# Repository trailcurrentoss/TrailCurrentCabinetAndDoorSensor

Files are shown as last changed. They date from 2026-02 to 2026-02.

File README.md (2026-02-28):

# TrailCurrent Cabinet and Door Sensor

Sensor module that monitors cabinet and door open/closed states using reed switches and reports status over a CAN bus interface. Part of the [TrailCurrent](https://trailcurrent.com) open-source vehicle platform.

## Hardware Overview

- **Microcontroller:** ESP32-C6
- **Function:** Cabinet and door state monitoring with CAN bus reporting
- **Key Features:**
  - 10 reed switch inputs for open/closed detection
  - CAN bus communication at 500 kbps
  - DIP switch selectable CAN address (up to 8 modules per bus)
  - Over-the-air (OTA) firmware updates via WiFi (triggered over CAN)
  - RGB LED status indicator
  - Custom flash partition layout with dual OTA slots
  - FreeCAD enclosure design

### Design Specifications

- **Operating Temperature:** -20°C to +70°C
- **Power:** 12V vehicle house battery via 5V DC-DC converter and 3.3V regulator
- **Data Rate:** 5 transmissions per second
- **Target Cost:** < $5 per unit

## CAN Bus Addressing

Each module uses a 3-position DIP switch to select its CAN message ID from a reserved block of 8 IDs (0x0A-0x11). This allows up to 8 modules on the same CAN bus, each reporting the state of up to 10 doors/cabinets.

| DIP SW3 | DIP SW2 | DIP SW1 | Address | CAN ID | DBC Message Name |
|---|---|---|---|---|---|
| OFF | OFF | OFF | 0 | 0x0A | CabinetDoorStatus0 |
| OFF | OFF | ON | 1 | 0x0B | CabinetDoorStatus1 |
| OFF | ON | OFF | 2 | 0x0C | CabinetDoorStatus2 |
| OFF | ON | ON | 3 | 0x0D | CabinetDoorStatus3 |
| ON | OFF | OFF | 4 | 0x0E | CabinetDoorStatus4 |
| ON | OFF | ON | 5 | 0x0F | CabinetDoorStatus5 |
| ON | ON | OFF | 6 | 0x10 | CabinetDoorStatus6 |
| ON | ON | ON | 7 | 0x11 | CabinetDoorStatus7 |

DIP switch position 4 enables the 120-ohm CAN bus termination resistor.

### CAN Message Format

Each module transmits a 2-byte message at 5 Hz (200 ms interval):

| Byte | Bits  | Description |
|---|---|---|
| 0 | 0-7 | Door status 1-8 (RSW01-RSW08) |
| 1 | 0-1 | Door status 9-10 (RSW09-RSW10) |
| 1 | 2-7 | Reserved |

Each bit represents one reed switch: `1` = door open, `0` = door closed.

### CAN Control Messages

The module also listens for control messages from other nodes:

- **CAN ID 0x00 - OTA Update Notification:** Contains a 3-byte MAC address suffix. If it matches this module's hostname, the module connects to WiFi using stored credentials and enters OTA update mode.
- **CAN ID 0x01 - WiFi Credential Configuration:** Multi-message protocol to receive and store WiFi SSID and password in NVS flash for future OTA updates.

## Hardware Requirements

### Components

- **Microcontroller:** ESP32-C6-Super-Mini
- **CAN Transceiver:** SN65HVD230
- **Sensors:** Normally Open (NO) reed switches
- **Address Selection:** 4-position DIP switch (3 address bits + CAN termination)
- **Power:** Buck converter (12V to 5V to 3.3V)
- **Connectors:** JST XH 2.54 4-pin

### KiCAD Library Dependencies

This project uses the consolidated [TrailCurrentKiCADLibraries](https://github.com/trailcurrentoss/TrailCurrentKiCADLibraries).

**Setup:**

```bash
# Clone the library alongside this project
git clone git@github.com:trailcurrentoss/TrailCurrentKiCADLibraries.git

# Set environment variables (add to ~/.bashrc or ~/.zshrc)
# Adjust paths to where you cloned the library
export TRAILCURRENT_SYMBOL_DIR="../TrailCurrentKiCADLibraries/symbols"
export TRAILCURRENT_FOOTPRINT_DIR="../TrailCurrentKiCADLibraries/footprints"
export TRAILCURRENT_3DMODEL_DIR="../TrailCurrentKiCADLibraries/3d_models"
```

See [KICAD_ENVIRONMENT_SETUP.md](https://github.com/trailcurrentoss/TrailCurrentKiCADLibraries/blob/main/KICAD_ENVIRONMENT_SETUP.md) in the library repository for detailed setup instructions.

### GPIO Pin Assignments

| GPIO  | Function | Notes |
|---|---|---|
| 0-7 | RSW03-RSW10 | Reed switch inputs (internal pull-up) |
| 8 | RGB LED | Built-in WS2812 on ESP32-C6 SuperMini |
| 14 | CAN TX | To SN65HVD230 transceiver |
| 15 | CAN RX | From SN65HVD230 transceiver |
| 16 | RSW01 | TX pin, free since USB CDC is used |
| 17 | RSW02 | RX pin, free since USB CDC is used |
| 18-20 | ADDR01-03 | DIP switch address bits (internal pull-up)|

## Opening the Project

1. **Set up environment variables** (see Library Dependencies above)
2. **Open KiCAD:**
   ```bash
   kicad EDA/TrailCurrentCabinetAndDoorSensorModule/TrailCurrentCabinetAndDoorSensorModule.kicad_pro
   ```
3. **Verify libraries load** - All symbol and footprint libraries should resolve without errors
4. **View 3D models** - Open PCB and press `Alt+3` to view the 3D visualization

## Firmware

See `src/` directory for PlatformIO-based firmware.

**Setup:**
```bash
# Install PlatformIO (if not already installed)
pip install platformio

# Build firmware
pio run

# Upload to board (serial)
pio run -t upload

# Upload via OTA (after initial flash)
pio run -t upload --upload-port esp32c6-DEVICE_ID
```

### Firmware Dependencies

This firmware depends on the following public libraries:

- **[C6SuperMiniRgbLedLibrary](https://github.com/trailcurrentoss/C6SuperMiniRgbLedLibrary)** (v0.0.1) - RGB LED status indicator driver
- **[Esp32C6OtaUpdateLibrary](https://github.com/trailcurrentoss/Esp32C6OtaUpdateLibrary)** (v0.0.1) - Over-the-air firmware update functionality
- **[Esp32C6TwaiTaskBasedLibrary](https://github.com/trailcurrentoss/Esp32C6TwaiTaskBasedLibrary)** (v0.0.3) - CAN bus communication interface
- **[ESP32ArduinoDebugLibrary](https://github.com/trailcurrentoss/ESP32ArduinoDebugLibrary)** - Debug macros with compile-time removal

All dependencies are automatically resolved by PlatformIO during the build process.

## Manufacturing

- **PCB Files:** Ready for fabrication via standard PCB services (JLCPCB, OSH Park, etc.)
- **BOM Generation:** Export BOM from KiCAD schematic (Tools > Generate BOM)
- **Enclosure:** FreeCAD design included in `CAD/` directory
- **JLCPCB Assembly:** See [BOM_ASSEMBLY_WORKFLOW.md](https://github.com/trailcurrentoss/TrailCurrentKiCADLibraries/blob/main/BOM_ASSEMBLY_WORKFLOW.md) for detailed assembly workflow

## Documentation

- **Requirements:** See `DOCS/Requirements/high-level-requirements.md` for detailed specifications

## Project Structure

```
├── CAD/                          # FreeCAD enclosure design
├── DOCS/                         # Requirements documentation
│   └── Requirements/
│       └── high-level-requirements.md
├── EDA/                          # KiCAD hardware design files
│   └── TrailCurrentCabinetAndDoorSensorModule/
│       ├── *.kicad_pro           # KiCAD project
│       ├── *.kicad_sch           # Schematic
│       └── *.kicad_pcb           # PCB layout
├── src/                          # Firmware source
│   └── main.cpp                  # Main application
├── platformio.ini                # Build configuration
└── partitions.csv                # ESP32 flash partition layout
```

## License

MIT License - See LICENSE file for details.

This is open source hardware. You are free to use, modify, and distribute these designs for personal or commercial purposes.

## Contributing

Improvements and contributions are welcome! Please submit issues or pull requests.

## Support

For questions about:
- **KiCAD setup:** See [KICAD_ENVIRONMENT_SETUP.md](https://github.com/trailcurrentoss/TrailCurrentKiCADLibraries/blob/main/KICAD_ENVIRONMENT_SETUP.md)
- **Assembly workflow:** See [BOM_ASSEMBLY_WORKFLOW.md](https://github.com/trailcurrentoss/TrailCurrentKiCADLibraries/blob/main/BOM_ASSEMBLY_WORKFLOW.md)

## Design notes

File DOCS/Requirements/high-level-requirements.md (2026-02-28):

# High-Level Design (HLD) Document

## 1. Project Overview

**Project Title:** Cabinet and Door Sensing Module

**Description:** A microcontroller-based system that monitors the status of doors and cabinets. It will be used to make the high level system contextually aware of which doors and or cabinets are currently open or closed.

**Objective:**  
To design and implement a reliable, low-power, and cost-effective microcontroller-based system for cabinet and door status monitoring that can operate autonomously and send data over the CAN bus.

---

## 2. Microcontroller Selection

**Selected Microcontroller:**  
**ESP32C6**  
[Datasheet](https://documentation.espressif.com/esp32-c6_datasheet_en.pdf)

**Rationale for Selection:**  
- Power efficient and built in can transceiver.  
- Low price point and availability as MCU, Module, or small footprint dev board.  
- Low power consumption.  
- Strong ecosystem and development support.

---

## 3. System Requirements

### 3.1 Functional Requirements

| Requirement | Description |
|---|---|
| Door Sensing | Read and send over CAN bus the door or cabinet status |
| Data Transmission | Send collected data to the rest of the network via CAN protocol |
| Power Management | Support for low-power modes to reduce load on installed environment |

### 3.2 Non-Functional Requirements

| Requirement | Description |
|---|---|
| Reliability | System must operate continuously without disruption indefinitely for solar installs |
| CAN Bus Data Usage | **Needs calculation to see what is available on a 500k CAN Bus.** |
| Environmental Tolerance | Operate within -20°C to +70°C |
| Cost | Target cost < $5 per unit |
---

## 4. System Architecture Overview

### 4.1 Hardware Components

| Component | Description |
|---|---|
| ESP32C6 | Main microcontroller |
| Reed Swith | Any brand should suffice, justt needs to provide an on/off state to trigger correctly. |

### 4.2 Software Components

| Component | Description |
|---|---|
| Main Application | Main data collection, and transmission |
| Sensor Drivers | Interface with reed switches |
| Communication Stack | CAN Bus coomunication implementation |
| OTA | Over the air update capabilities with trigger coming from CAN Bus. |

---

## 5. Communication Protocol

- **CAN Bus:** CAN Bus protocol used to transmit data  
- **Data Format:** Binary representation of each sensor status
- **Transmission Frequency:** 5 times per second to avoid delayed notification of doors changing status during travel.
---

## 6. Power Management Strategy

- **Battery:** Connected to house battery of implemented vehicle.
- **Power Supply Circuit:** 5V DC to DC buck converter with 3.3V regulator (e.g., AMS1117)  
---

## 7. Development Tools and Environment

| Tool | Description |
|---|---|
| PioArduino | Development IDE |
| Arduino | Framework used for firmware |
| KiCAD | EDA Design tool for schematic and PCB |
| FreeCAD | CAD tool used for enclosure design |
| Version Control | Git with GitHub for repo and source control |
| Documentation Tools | Markdown |

---

## 8. Testing and Validation

| Test Type | Description |
|---|---|
| Unit Testing | Test individual modules (e.g., sensor drivers, communication stack) |
| Integration Testing | Ensure all components work together as expected |
| Performance Testing | Measure power consumption, response time, and data accuracy |
---

## 9. Future Enhancements

- Add GPS module for location tracking  
- Support for multiple sensors (e.g., PM2.5, CO2)  
- Edge computing for local data processing  
- Integration with IoT platforms (e.g., AWS IoT, Azure IoT Hub)  
- Mobile app integration for real-time monitoring

---

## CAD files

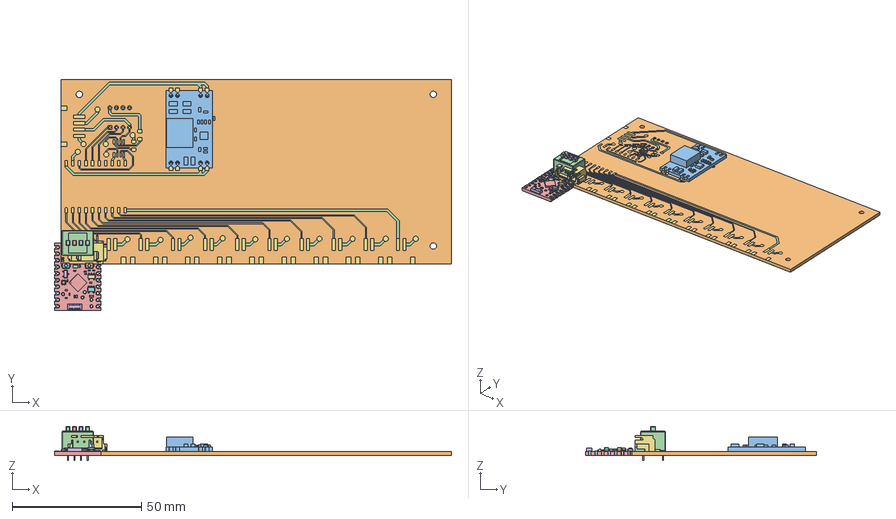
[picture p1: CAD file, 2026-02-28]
CAD/TrailCurrentCabinetAndDoorSensorModuleEDA.FCStd
153.4 x 89.4 x 13.2 mm
SxB-XH-SM4-TB
SxB-XH-SM4-TB001
SxB-XH-SM4-TB002
BODY-SO
LEAD-D0008A
LEAD-D0008A001
LEAD-D0008A002
LEAD-D0008A003
LEAD-D0008A004
LEAD-D0008A005
LEAD-D0008A006
LEAD-D0008A007
PCB
USB_C_Receptacle_16P_TopMnt_Horizontal_GCT_USB4105-xx-A037
USB_C_Receptacle_16P_TopMnt_Horizontal_GCT_USB4105-xx-A038
USB_C_Receptacle_16P_TopMnt_Horizontal_GCT_USB4105-xx-A039
USB_C_Receptacle_16P_TopMnt_Horizontal_GCT_USB4105-xx-A040
USB_C_Receptacle_16P_TopMnt_Horizontal_GCT_USB4105-xx-A041
USB_C_Receptacle_16P_TopMnt_Horizontal_GCT_USB4105-xx-A042
USB_C_Receptacle_16P_TopMnt_Horizontal_GCT_USB4105-xx-A043
USB_C_Receptacle_16P_TopMnt_Horizontal_GCT_USB4105-xx-A044
USB_C_Receptacle_16P_TopMnt_Horizontal_GCT_USB4105-xx-A045
USB_C_Receptacle_16P_TopMnt_Horizontal_GCT_USB4105-xx-A046
USB_C_Receptacle_16P_TopMnt_Horizontal_GCT_USB4105-xx-A047
USB_C_Receptacle_16P_TopMnt_Horizontal_GCT_USB4105-xx-A048
USB_C_Receptacle_16P_TopMnt_Horizontal_GCT_USB4105-xx-A049
USB_C_Receptacle_16P_TopMnt_Horizontal_GCT_USB4105-xx-A050
USB_C_Receptacle_16P_TopMnt_Horizontal_GCT_USB4105-xx-A051
USB_C_Receptacle_16P_TopMnt_Horizontal_GCT_USB4105-xx-A052
USB_C_Receptacle_16P_TopMnt_Horizontal_GCT_USB4105-xx-A053
USB_C_Receptacle_16P_TopMnt_Horizontal_GCT_USB4105-xx-A054
USB_C_Receptacle_16P_TopMnt_Horizontal_GCT_USB4105-xx-A055
USB_C_Receptacle_16P_TopMnt_Horizontal_GCT_USB4105-xx-A056
USB_C_Receptacle_16P_TopMnt_Horizontal_GCT_USB4105-xx-A057
USB_C_Receptacle_16P_TopMnt_Horizontal_GCT_USB4105-xx-A058
USB_C_Receptacle_16P_TopMnt_Horizontal_GCT_USB4105-xx-A059
USB_C_Receptacle_16P_TopMnt_Horizontal_GCT_USB4105-xx-A060
USB_C_Receptacle_16P_TopMnt_Horizontal_GCT_USB4105-xx-A061
USB_C_Receptacle_16P_TopMnt_Horizontal_GCT_USB4105-xx-A062
USB_C_Receptacle_16P_TopMnt_Horizontal_GCT_USB4105-xx-A063
USB_C_Receptacle_16P_TopMnt_Horizontal_GCT_USB4105-xx-A064
USB_C_Receptacle_16P_TopMnt_Horizontal_GCT_USB4105-xx-A065
USB_C_Receptacle_16P_TopMnt_Horizontal_GCT_USB4105-xx-A066
USB_C_Receptacle_16P_TopMnt_Horizontal_GCT_USB4105-xx-A067
USB_C_Receptacle_16P_TopMnt_Horizontal_GCT_USB4105-xx-A068
USB_C_Receptacle_16P_TopMnt_Horizontal_GCT_USB4105-xx-A069
USB_C_Receptacle_16P_TopMnt_Horizontal_GCT_USB4105-xx-A070
USB_C_Receptacle_16P_TopMnt_Horizontal_GCT_USB4105-xx-A071
USB_C_Receptacle_16P_TopMnt_Horizontal_GCT_USB4105-xx-A072
Button_black_002
Button_black_003
io23
io21
io22
io12
io13
Corps
Corps001
Corps002
Corps003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

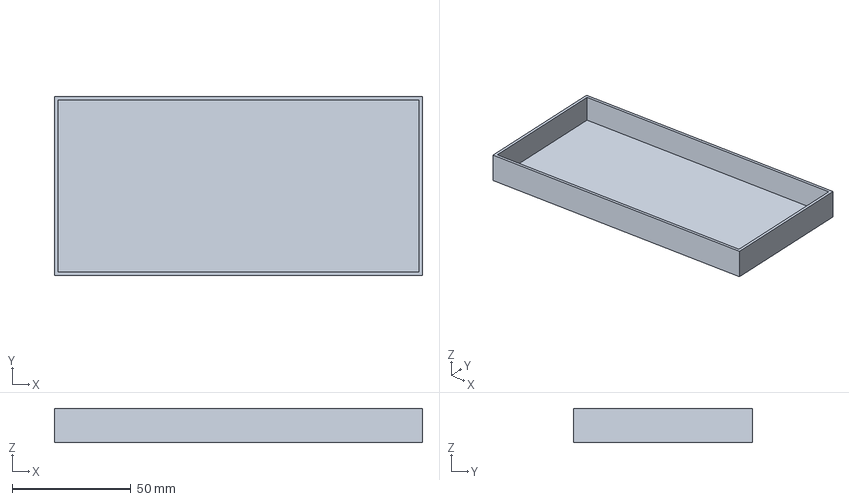
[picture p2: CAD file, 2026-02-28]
CAD/TrailCurrentCabinetAndDoorSensorModuleHousing.FCStd
154.8 x 75.2 x 14.5 mm

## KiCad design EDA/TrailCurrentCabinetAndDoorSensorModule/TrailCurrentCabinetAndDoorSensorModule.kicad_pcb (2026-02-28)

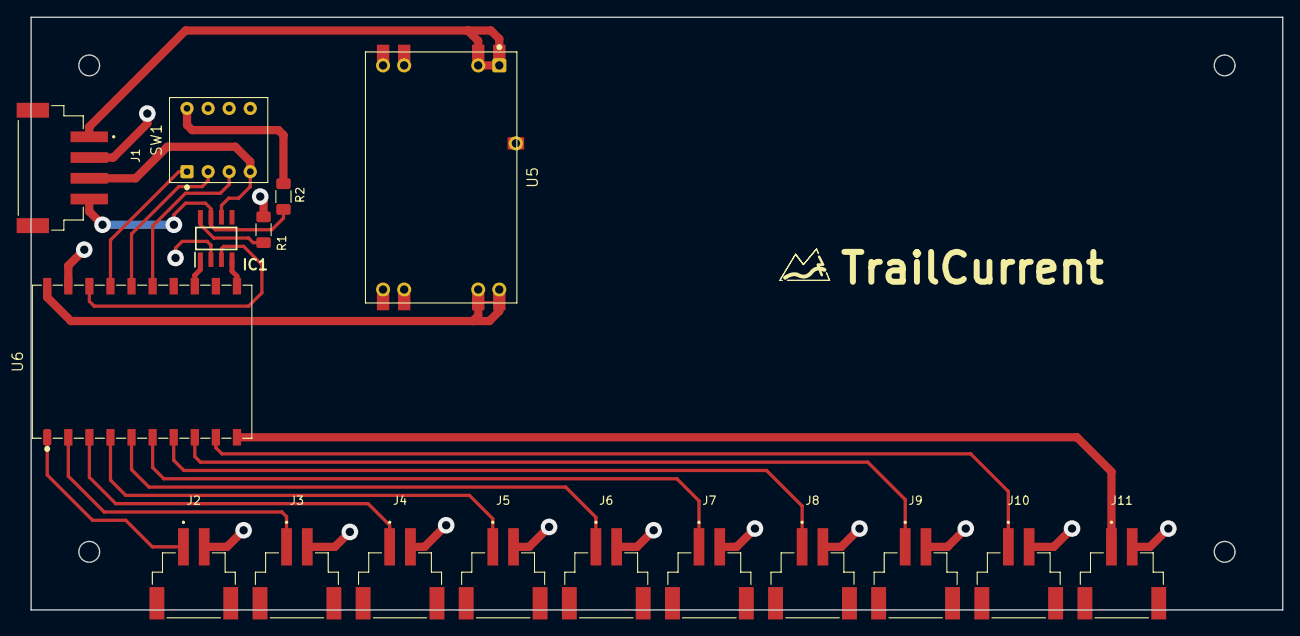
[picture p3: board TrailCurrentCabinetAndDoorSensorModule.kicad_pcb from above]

Board: 2 copper layers, 150.8 x 71.4 mm, 19 parts (0 on the bottom side), 23 nets.

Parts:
IC1: SN65HVD230DR
J1: S4B-XH-SM4-TB; JST_S4B-XH-SM4-TB
J2, J3, J4, J5, J6, J7, J8, J9, J10, J11: S2B-XH-SM4-TB; JST_S2B-XH-SM4-TB
LOGO: TrailCurrentLogo_Text
LOGO#2: TrailCurrentLogo_Icon
R1: 10k; R_1206_3216Metric_Pad1.30x1.75mm_HandSolder
R2: 120; R_1206_3216Metric_Pad1.30x1.75mm_HandSolder
SW1: DS-04
U5: Mini560
U6: ESP32-C6-SuperMini; ESP32-C6-SuperMini_SMD

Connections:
+3.3V: IC1.3 (VCC), U6.13 (3V3)
+5V: U5.8 (VOUT+), U5.9 (VOUT+), U6.11 (5V)
+12V: J1.1, U5.1 (VIN+), U5.2 (VIN+)
ADDR01: SW1.3, U6.16 (GPIO18)
ADDR02: SW1.2, U6.15 (GPIO19)
ADDR03: SW1.1, U6.14 (GPIO20)
CANH: IC1.7 (CANH), J1.4, R2.1
CANL: IC1.6 (CANL), J1.3, SW1.4
CAN_RX: IC1.4 (R), U6.20 (GPIO8)
CAN_TX: IC1.1 (D), U6.18 (GPIO14)
GND: IC1.2 (GND), J1.2, J2.2, J3.2, J4.2, J5.2, J6.2, J7.2, J8.2, J9.2, J10.2, J11.2, R1.1, SW1.5, SW1.6, SW1.7, U5.3 (GND), U5.4 (GND), U5.6 (GND), U5.7 (GND), U6.12 (GND)
unnamed: IC1.8 (RS), R1.2
unnamed: R2.2, SW1.8
RSW01: J2.1, U6.1 (TX)
RSW02: J3.1, U6.2 (RX)
RSW03: J4.1, U6.3 (GPIO0)
RSW04: J5.1, U6.4 (GPIO1)
RSW05: J6.1, U6.5 (GPIO2)
RSW06: J7.1, U6.6 (GPIO3)
RSW07: J8.1, U6.7 (GPIO4)
RSW08: J9.1, U6.8 (GPIO5)
RSW09: J10.1, U6.9 (GPIO6)
RSW10: J11.1, U6.10 (GPIO7)

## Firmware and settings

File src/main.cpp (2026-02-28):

#include <Arduino.h>
#include <debug.h>
#include "OtaUpdate.h"
#include "RgbLed.h"
#include "TwaiTaskBased.h"
#include <Preferences.h>
#include <driver/gpio.h>

// =============================================================================
// Pin Definitions (from schematic global labels)
// =============================================================================

// Reed switch inputs (Normally Open - close when magnet nearby / door closed)
// HIGH = door open, LOW = door closed (using internal pull-ups)
static const gpio_num_t RSW_PINS[] = {
  GPIO_NUM_16,  // RSW01 (TX pin - free since USB CDC is used for Serial)
  GPIO_NUM_17,  // RSW02 (RX pin - free since USB CDC is used for Serial)
  GPIO_NUM_0,   // RSW03
  GPIO_NUM_1,   // RSW04
  GPIO_NUM_2,   // RSW05
  GPIO_NUM_3,   // RSW06
  GPIO_NUM_4,   // RSW07
  GPIO_NUM_5,   // RSW08
  GPIO_NUM_6,   // RSW09
  GPIO_NUM_7,   // RSW10
};
static const uint8_t NUM_RSW = sizeof(RSW_PINS) / sizeof(RSW_PINS[0]);

// DIP switch address pins (active LOW - switches pull to GND when ON)
static const gpio_num_t ADDR_PINS[] = {
  GPIO_NUM_18,  // ADDR01 (bit 0 - LSB)
  GPIO_NUM_19,  // ADDR02 (bit 1)
  GPIO_NUM_20,  // ADDR03 (bit 2 - MSB)
};
static const uint8_t NUM_ADDR_PINS = sizeof(ADDR_PINS) / sizeof(ADDR_PINS[0]);

// CAN bus pins
static const gpio_num_t CAN_TX_PIN = GPIO_NUM_14;
static const gpio_num_t CAN_RX_PIN = GPIO_NUM_15;

// RGB LED (built-in WS2812 on GPIO8)
static const uint8_t RGB_LED_PIN = 8;

// =============================================================================
// CAN Bus Configuration
// =============================================================================

// CAN IDs 0x0A-0x11 reserved for up to 8 Cabinet/Door Sensor modules.
// Higher priority (lower ID) than DeviceStatusReport (0x1B).
// DIP switches select offset: CAN_ID = CAN_BASE_ID + dip_value (0-7)
static const uint32_t CAN_BASE_ID = 0x0A;
static const uint32_t CAN_BAUDRATE = 500000;

// Transmit interval (200ms = 5 Hz)
static const unsigned long TX_INTERVAL_MS = 200;

// Debounce time for reed switch readings
static const unsigned long DEBOUNCE_MS = 50;

// =============================================================================
// Global State
// =============================================================================

RgbLed statusLed(RGB_LED_PIN);
OtaUpdate otaUpdate(statusLed, 180000, "", "");

uint32_t canMessageId = CAN_BASE_ID;
unsigned long lastTxTime = 0;

// Debounced reed switch state
uint16_t debouncedState = 0;
uint16_t lastRawState = 0;
unsigned long lastChangeTime = 0;

// WiFi credential reception state (CAN ID 0x01 protocol)
bool wifiConfigInProgress = false;
uint8_t wifiSsidBuffer[33];
uint8_t wifiPasswordBuffer[64];
uint8_t wifiSsidLen = 0;
uint8_t wifiPasswordLen = 0;
uint8_t wifiSsidReceived = 0;
uint8_t wifiPasswordReceived = 0;

// =============================================================================
// WiFi Credential Storage
// =============================================================================

void saveWifiCredentials(const char* ssid, const char* password) {
  Preferences prefs;
  prefs.begin("wifi", false);
  prefs.putString("ssid", ssid);
  prefs.putString("password", password);
  prefs.end();
  debugf("[WiFi] Credentials saved to NVS (SSID: %s)\n", ssid);
}

void handleWifiConfigMessage(const twai_message_t &msg) {
  uint8_t msgType = msg.data[0];

  switch (msgType) {
    case 0x01: {
      wifiSsidLen = msg.data[1];
      wifiPasswordLen = msg.data[2];
      wifiSsidReceived = 0;
      wifiPasswordReceived = 0;
      memset(wifiSsidBuffer, 0, sizeof(wifiSsidBuffer));
      memset(wifiPasswordBuffer, 0, sizeof(wifiPasswordBuffer));
      wifiConfigInProgress = true;
      debugf("[WiFi] Config start: SSID len=%d, Password len=%d\n",
             wifiSsidLen, wifiPasswordLen);
      break;
    }
    case 0x02: {
      if (!wifiConfigInProgress) break;
      uint8_t dataBytes = msg.data_length_code - 2;
      uint8_t remaining = wifiSsidLen - wifiSsidReceived;
      if (dataBytes > remaining) dataBytes = remaining;
      if (wifiSsidReceived + dataBytes <= 32) {
        memcpy(wifiSsidBuffer + wifiSsidReceived, &msg.data[2], dataBytes);
        wifiSsidReceived += dataBytes;
      }
      break;
    }
    case 0x03: {
      if (!wifiConfigInProgress) break;
      uint8_t dataBytes = msg.data_length_code - 2;
      uint8_t remaining = wifiPasswordLen - wifiPasswordReceived;
      if (dataBytes > remaining) dataBytes = remaining;
      if (wifiPasswordReceived + dataBytes <= 63) {
        memcpy(wifiPasswordBuffer + wifiPasswordReceived, &msg.data[2], dataBytes);
        wifiPasswordReceived += dataBytes;
      }
      break;
    }
    case 0x04: {
      if (!wifiConfigInProgress) break;
      wifiConfigInProgress = false;

      uint8_t checksum = 0;
      for (uint8_t i = 0; i < wifiSsidReceived; i++) checksum ^= wifiSsidBuffer[i];
      for (uint8_t i = 0; i < wifiPasswordReceived; i++) checksum ^= wifiPasswordBuffer[i];

      if (checksum == msg.data[1] &&
          wifiSsidReceived == wifiSsidLen &&
          wifiPasswordReceived == wifiPasswordLen) {
        wifiSsidBuffer[wifiSsidReceived] = '\0';
        wifiPasswordBuffer[wifiPasswordReceived] = '\0';
        saveWifiCredentials((const char*)wifiSsidBuffer,
                            (const char*)wifiPasswordBuffer);
      } else {
        debugf("[WiFi] Config failed: checksum %s, SSID %d/%d, Password %d/%d\n",
               (checksum == msg.data[1]) ? "OK" : "MISMATCH",
               wifiSsidReceived, wifiSsidLen,
               wifiPasswordReceived, wifiPasswordLen);
      }
      break;
    }
  }
}

// =============================================================================
// CAN Bus Callbacks
// =============================================================================

void onCanRx(const twai_message_t &msg) {
  if (msg.identifier == 0x00) {
    // OTA update notification - check if it's for this device
    char updateForHostName[14];
    String currentHostName = otaUpdate.getHostName();
    sprintf(updateForHostName, "esp32c6-%X%X%X",
            msg.data[0], msg.data[1], msg.data[2]);

    if (currentHostName.equals(updateForHostName)) {
      debugln("[OTA] Hostname matched - reading WiFi credentials from NVS");

      Preferences prefs;
      prefs.begin("wifi", true);
      String ssid = prefs.getString("ssid", "");
      String password = prefs.getString("password", "");
      prefs.end();

      if (ssid.length() > 0 && password.length() > 0) {
        debugf("[OTA] Using stored WiFi credentials (SSID: %s)\n", ssid.c_str());
        OtaUpdate ota(statusLed, 180000, ssid.c_str(), password.c_str());
        ota.waitForOta();
        debugln("[OTA] OTA mode exited - resuming normal operation");
      } else {
        debugln("[OTA] ERROR: No WiFi credentials in NVS - cannot start OTA");
      }
    }
  } else if (msg.identifier == 0x01) {
    handleWifiConfigMessage(msg);
  }
}

void onCanTx(bool ok) {
  debug_if(!ok, "[CAN] TX FAIL");
}

// =============================================================================
// Reed Switch Reading
// =============================================================================

uint16_t readReedSwitches() {
  uint16_t state = 0;
  for (uint8_t i = 0; i < NUM_RSW; i++) {
    // HIGH = door open (pull-up, NO reed switch open)
    // LOW = door closed (reed switch closed by magnet)
    if (digitalRead(RSW_PINS[i]) == HIGH) {
      state |= (1 << i);
    }
  }
  return state;
}

uint16_t readDebouncedSwitches() {
  uint16_t rawState = readReedSwitches();

  if (rawState != lastRawState) {
    lastRawState = rawState;
    lastChangeTime = millis();
  }

  if ((millis() - lastChangeTime) >= DEBOUNCE_MS) {
    debouncedState = rawState;
  }

  return debouncedState;
}

// =============================================================================
// DIP Switch Address Reading
// =============================================================================

uint8_t readDipAddress() {
  uint8_t addr = 0;
  for (uint8_t i = 0; i < NUM_ADDR_PINS; i++) {
    // DIP switches pull to GND when ON (active LOW with pull-up)
    // ON = LOW = bit set
    if (digitalRead(ADDR_PINS[i]) == LOW) {
      addr |= (1 << i);
    }
  }
  return addr;
}

// =============================================================================
// CAN Message Transmission
// =============================================================================

void sendDoorStatus(uint16_t doorState) {
  twai_message_t msg = {};
  msg.identifier = canMessageId;
  msg.data_length_code = 2;

  // Byte 0: RSW01-RSW08 (bits 0-7), 1=open, 0=closed
  msg.data[0] = (uint8_t)(doorState & 0xFF);

  // Byte 1: RSW09-RSW10 (bits 0-1), bits 2-7 reserved
  msg.data[1] = (uint8_t)((doorState >> 8) & 0x03);

  TwaiTaskBased::send(msg);
}

// =============================================================================
// Setup
// =============================================================================

void setup() {
  Serial.begin(115200);
#if DEBUG == 0
  Serial.println("Debug disabled - no further serial output.");
#else
  debugln("[INIT] Cabinet & Door Sensor starting");
#endif

  // Initialize RGB LED (built-in WS2812 on GPIO8)
  statusLed.begin();
  statusLed.setBrightnessPercent(1);

  // Configure reed switch inputs with internal pull-ups
  for (uint8_t i = 0; i < NUM_RSW; i++) {
    pinMode(RSW_PINS[i], INPUT_PULLUP);
  }
  debugf("[INIT] Configured %d reed switch inputs\n", NUM_RSW);

  // Configure DIP switch address pins with internal pull-ups
  for (uint8_t i = 0; i < NUM_ADDR_PINS; i++) {
    pinMode(ADDR_PINS[i], INPUT_PULLUP);
  }

  // Read DIP switch address and compute CAN message ID
  uint8_t dipAddr = readDipAddress();
  canMessageId = CAN_BASE_ID + dipAddr;
  debugf("[INIT] DIP address: %d, CAN ID: 0x%02X\n", dipAddr, canMessageId);

  // Initialize CAN bus
  TwaiTaskBased::onReceive(onCanRx);
  TwaiTaskBased::onTransmit(onCanTx);
  TwaiTaskBased::begin(CAN_TX_PIN, CAN_RX_PIN, CAN_BAUDRATE);
  debugln("[INIT] TWAI started on GPIO14 (TX) / GPIO15 (RX)");

  // Read initial state
  debouncedState = readReedSwitches();
  lastRawState = debouncedState;
  lastChangeTime = millis();

  debugf("[INIT] Initial door state: 0x%04X\n", debouncedState);
  statusLed.green();
  debugln("[INIT] Setup complete");
}

// =============================================================================
// Main Loop
// =============================================================================

void loop() {
  uint16_t currentState = readDebouncedSwitches();

  unsigned long now = millis();
  if (now - lastTxTime >= TX_INTERVAL_MS) {
    lastTxTime = now;
    sendDoorStatus(currentState);
  }
}

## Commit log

2026-02-12 Starting project
    [TrailCurrentCabinetAndDoorSensorHousing.FCStd, TrailCurrentCabinetAndDoorSensorModule.kicad_pcb, TrailCurrentCabinetAndDoorSensorModule.kicad_sch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]
2026-02-28 Firmware added. Schematic added. CAD files started.
    [TrailCurrentCabinetAndDoorSensorHousing.FCStd, TrailCurrentCabinetAndDoorSensorModule.kicad_pcb, TrailCurrentCabinetAndDoorSensorModule.kicad_sch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]
